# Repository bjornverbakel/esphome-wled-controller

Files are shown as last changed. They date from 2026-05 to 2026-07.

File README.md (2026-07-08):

# ESPHome WLED Controller

An ESPHome-based controller for WLED-powered LED strips, integrated with Home Assistant. Features a 16x2 LCD display, rotary encoder for brightness, and a joystick-driven preset menu.

## Features

- **Brightness control** — rotary encoder adjusts WLED brightness (0-100%)
- **Power toggle** — rotary encoder push-button toggles WLED on/off
- **Preset menu** — joystick opens an on-screen menu to select WLED presets
- **LCD auto-blank** — display turns off after 10 seconds of inactivity
- **HA connection status** — LCD shows "No HA connection" when offline
- **3D-printable enclosure** — compact case for easy assembly



## Requirements

- ESPHome
- Home Assistant
- WLED integrated with Home Assistant
- ESP32 + listed hardware components

## 3D-printable enclosure

You can find the MakerWorld listing [here](https://makerworld.com/en/models/3025300-wled-controller-for-home-assistant-esphome).

Alternatively, the 3D files for this project are also included in this repository:

- Full assembly: [`3d/esphome-wled-controller.3mf`](3d/esphome-wled-controller.3mf)
- Individual parts: [`3d/parts/case.3mf`](3d/parts/case.3mf) and [`3d/parts/lid.3mf`](3d/parts/lid.3mf)



## Hardware

| Component | Details |
| --- | --- |
| Microcontroller | [Freenove ESP32 Dev Board (esp32dev, dual-core 240MHz)](https://amzn.eu/d/08tkQERI) |
| Display | [1602A QAPAS — 16x2 character LCD (HD44780, 4-bit parallel)](https://amzn.eu/d/035yjVYl) |
| Encoder | [KY-040 rotary encoder with push-button](https://amzn.eu/d/0c5rQTaQ) |
| Joystick | [KY-023 analog joystick with push-button](https://amzn.eu/d/0fTt9PCg) |
| Backlight control | 2N2222 NPN transistor + 1kΩ resistor |
| Contrast | 10kΩ multiturn trimmer potentiometer |

## Wiring

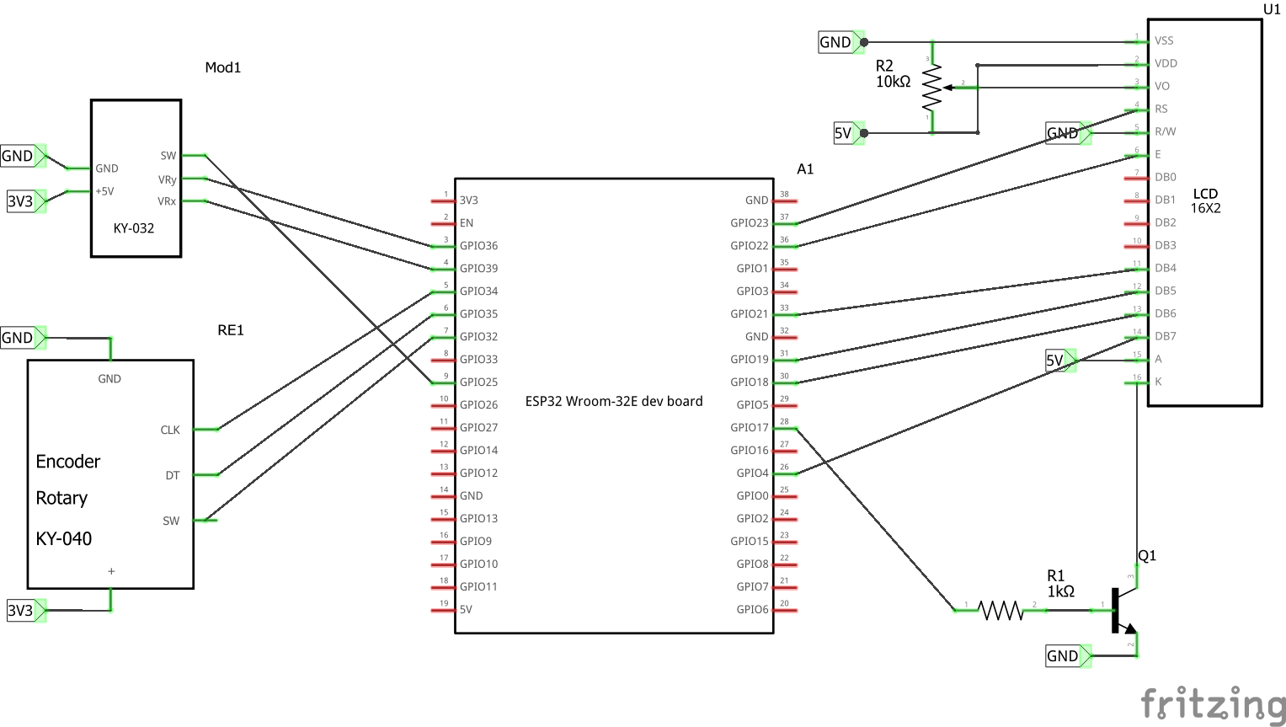
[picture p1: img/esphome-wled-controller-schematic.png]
Wiring Schematic


### LCD (16x2, HD44780)

| LCD Pin | Connection |
| --- | --- |
| 1 VSS | GND |
| 2 VDD | 5V |
| 3 V0 | Trimpot wiper |
| 4 RS | GPIO23 |
| 5 R/W | GND |
| 6 E | GPIO22 |
| 7-10 | Not connected |
| 11 DB4 | GPIO21 |
| 12 DB5 | GPIO19 |
| 13 DB6 | GPIO18 |
| 14 DB7 | GPIO4 |
| 15 A (backlight+) | 5V |
| 16 K (backlight-) | Transistor collector |

### Contrast trimpot

| Leg | Connection |
| --- | --- |
| 1 | 5V |
| 2 (wiper) | LCD pin 3 (V0) |
| 3 | GND |

### Backlight transistor (2N2222 NPN)

| Pin | Connection |
| --- | --- |
| Base | 1kΩ resistor → GPIO17 |
| Collector | LCD pin 16 (K) |
| Emitter | GND |

### Rotary encoder

| Pin | Connection |
| --- | --- |
| A | GPIO34 |
| B | GPIO35 |
| SW (push-button) | GPIO32 |

### Joystick

| Pin | Connection |
| --- | --- |
| Y axis | GPIO36 |
| X axis | GPIO39 |
| SW (push-button) | GPIO25 |

I recommend soldering the components onto a small perfboard for a more compact and durable setup. The rotary encoder, joystick, and LCD can be mounted on the lid of the enclosure with the screw terminals. The perfboard is mounted on the case with M2 screws, and the components are mounted on the lid with M3 screws.



It doesn't have to be the exact same, but this is roughly what I used (though you should space the components out a bit more to make it easier to solder).

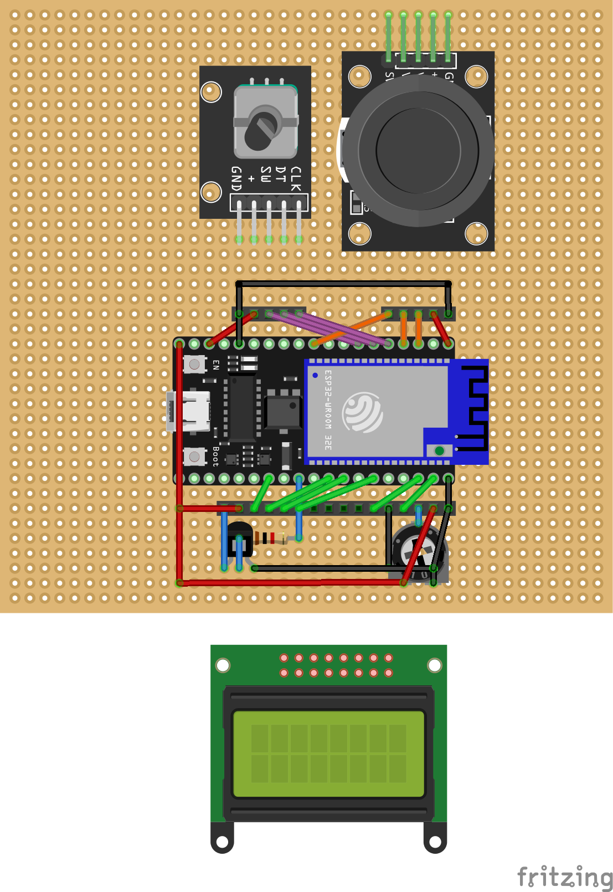
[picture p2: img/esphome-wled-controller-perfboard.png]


## Setup

1. Install [ESPHome](https://esphome.io/)
2. Copy [`secrets.yaml.example`](secrets.yaml.example) to your `secrets.yaml` and fill in the values
3. Update the `substitutions` block at the top of [`esp32-led-controller.yaml`](esp32-led-controller.yaml) to match your Home Assistant entity IDs:
   ```yaml
   substitutions:
     light_entity: light.your_wled_light
     preset_entity: select.your_wled_preset_selector
   ```
4. Flash the device
5. Add the device to Home Assistant via the ESPHome integration
6. Adjust the contrast trimpot until characters are visible on the LCD

## WLED Presets

### How presets work

The preset names in the config must **exactly match** the preset names you create in WLED.

### Create presets in WLED

1. Open the WLED web interface
2. Set up the effect, colours, and speed you want
3. Go to **Presets** → save the preset with the exact name listed below
4. Repeat for each preset you want

### Default Presets

These presets are already in [`esp32-led-controller.yaml`](esp32-led-controller.yaml) and must exist in WLED with these exact names if you wish to use the same presets as me:

- Candle Multi
- Colorwaves
- Fireworks
- Gradient
- Lake
- Noise 3
- Random Colors
- Solid

These are effects simply adjusted in color and speeds to my personal liking. You can add them to WLED manually or upload the `presets.json` file into WLED.

### Adding custom presets

To add your own presets to the selection menu, create it in WLED first, then add a new entry to the `lcd_menu` section in [`esp32-led-controller.yaml`](esp32-led-controller.yaml):

```yaml
- type: command
  text: "Your Preset Name"
  on_value:
    - homeassistant.action:
        action: select.select_option
        data:
          entity_id: ${preset_entity}
          option: "Your Preset Name"
    - display_menu.hide: preset_menu
    - script.execute: lcd_wake
```

Also update the `preset_count` global at the top of the config to match the new total number of presets:

```yaml
- id: preset_count
  type: int
  initial_value: "9" # change this to your new total
```

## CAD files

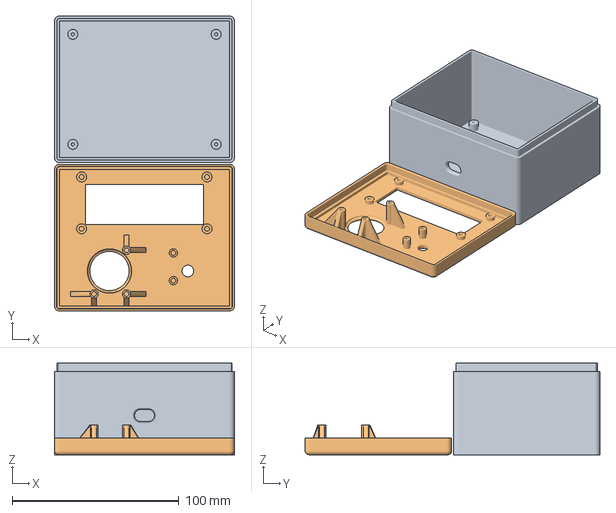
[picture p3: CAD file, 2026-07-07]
3d/esphome-wled-controller.3mf
108.0 x 177.0 x 55.0 mm
Case
Lid

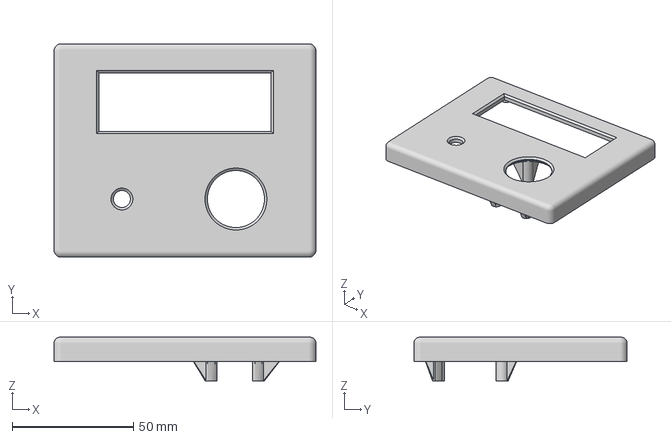
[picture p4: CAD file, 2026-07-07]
3d/parts/lid.3mf
108.0 x 88.0 x 18.0 mm

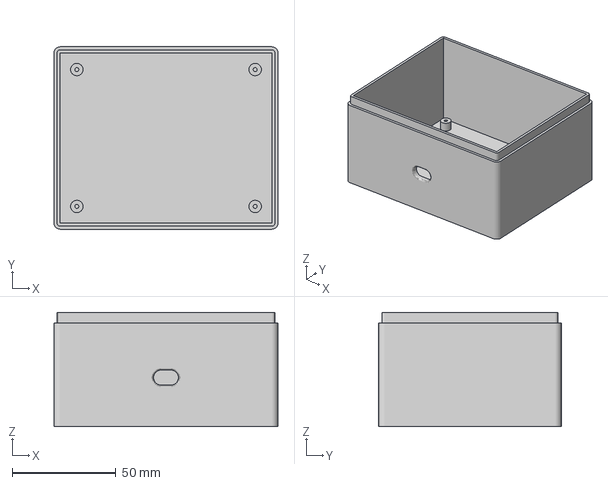
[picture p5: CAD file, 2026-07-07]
3d/parts/case.3mf
108.0 x 88.0 x 55.0 mm

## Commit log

2026-05-13 Add README
    Expanded README with detailed features, hardware, wiring, setup instructions, and WLED preset management.
2026-05-13 Add ESP32 WLED controller configuration
2026-05-13 Add wiring schematic image to README
    Added wiring schematic image to README.
2026-07-07 Add new files and update readme
    [case.3mf, esphome-wled-controller.3mf, lid.3mf]
